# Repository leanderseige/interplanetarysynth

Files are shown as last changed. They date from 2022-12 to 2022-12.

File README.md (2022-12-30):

# Interplanetary Synth

This is a DIY synthesizer project based on Bleeptrack's [Picoplanets](https://github.com/bleeptrack/Picoplanet).

Photo Interplanetary Synth

Features:
- 3 voices, polyphonic, based on PWM
- Recording and looped playback of sequences
- Pitch control
- PT2399-based echo/reverb unit
- Sync in/out jacks in order to sync the Interplanetary Synth with other analog synthesizers

After turning the synth on all three voices start in live-mode. When pressing and holding the button, the Picoplanet starts recording what is currently played. After releasing the button the Picoplanet immediately plays what was recorded. Looping starts with the next rising sync edge (after frequency dividing, see circuit). When pressing the button quickly (without touching any touch buttons) the Picoplanet returns into live-mode.

I am sure the software can be improved in several ways. Find the code.py right here in the root directory.

LEDs:
- Blue: live-mode, synth outputs what is currently played on the touch buttons
- Red: recording of what is currently played on the touch buttons
- Green: playback of recorded frequencies
- Purple: waiting for next rising edge of sync signal to restart playback

## Demo Video

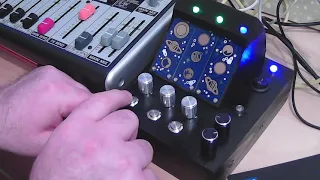
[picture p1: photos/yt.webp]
Demo Video (https://www.youtube.com/watch?v=XGoNoBU3fJs)


Here is a demo of how to use the Interplanetary Synth and how it sounds: https://www.youtube.com/watch?v=XGoNoBU3fJs

## Circuit Diagram

I hope that I have reproduced everything correctly in the circuit diagram. Use at your own risk.

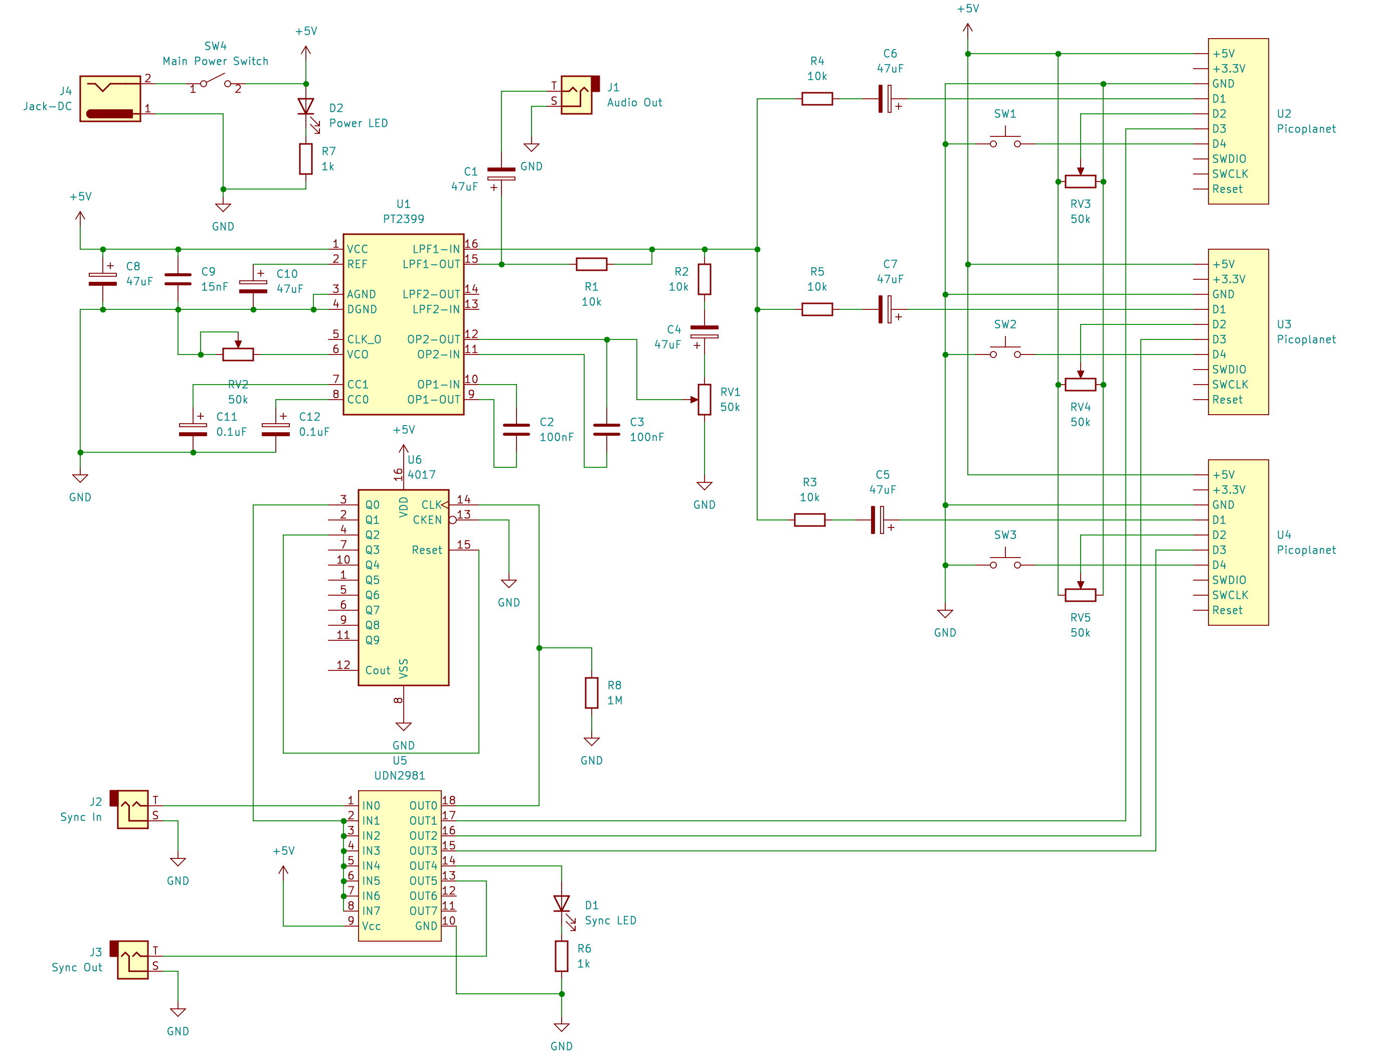
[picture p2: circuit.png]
Circuit Diagram of the Interplanetary Synth


The circuit consists of
- three Picoplanets,
- an Echo/Reverb unit (inspired by Peter Vis' https://www.petervis.com/guitar-circuits/pt2399/testing-and-troubleshooting.html but with important changes on Pins 2, 3 and 4 according to https://www.petervis.com/guitar-circuits/pt2399/basic-echo-circuit.html) and
- a unit to handle Sync signals using a CD4017 (frequency divider) and a UDN2981 (driver)

The four usable Pins of the Picoplanets work as PWM-Output, Potentiometer-Input, Push-Button-Input and Sync-Signal-Input.

## Case

I used a simple wooden box (https://amzn.to/3G5dJ2B) for housing everything except the Picoplanets and I painted it black. In order to get them up at a 45° angle to the user, I designed and printed a special top-case. Find the model in the folder '3dmodels'.

To make the LEDs visible, I drilled additional 5mm holes in the top case (I had forgotten to do this before) and pressed small pieces of 5mm fibre optic cable (https://amzn.to/3QgvRLP) into them. This worked surprisingly well. The light of the small LED appears really great at the end of the fibre cables.

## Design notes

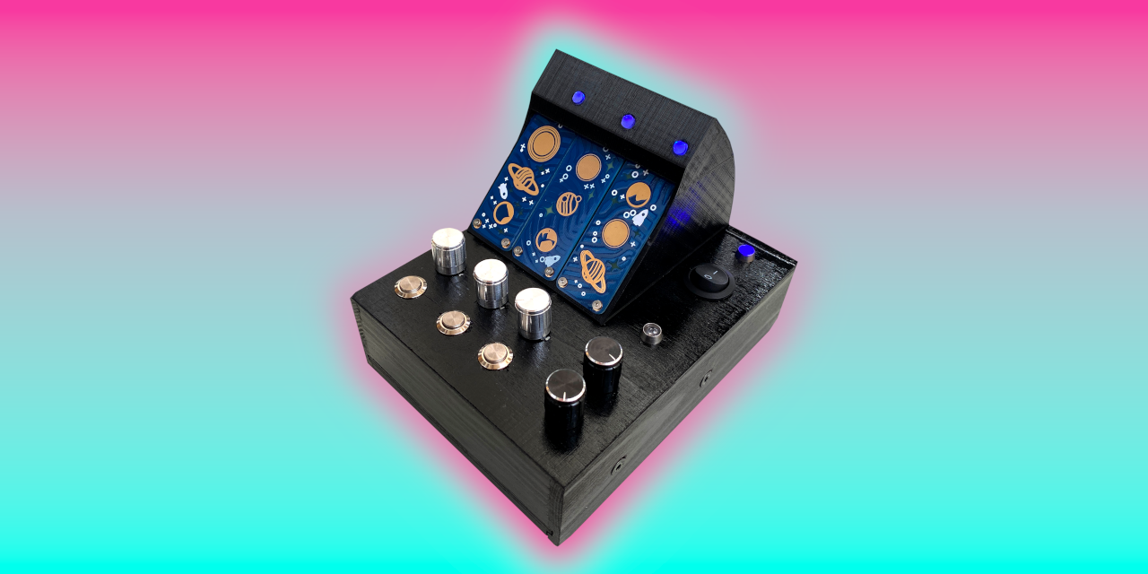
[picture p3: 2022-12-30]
photos/socialmedia.png

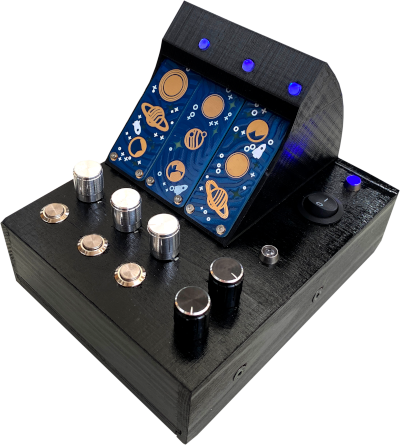
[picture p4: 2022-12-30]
photos/photo1small.png

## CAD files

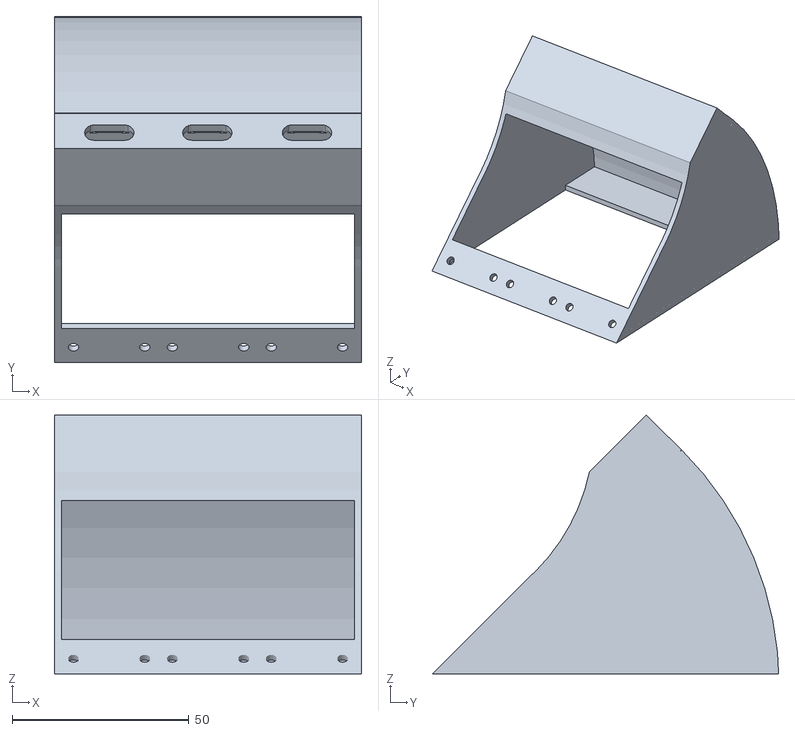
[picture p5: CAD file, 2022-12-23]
3dmodels/topcase.stl
87.0 x 98.0 x 73.3

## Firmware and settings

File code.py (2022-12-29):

#
# Software of the Interplanetary Synth, (c) 2022, Leander Seige
# Released under the terms of the GNU GPL V3
# https://github.com/leanderseige/interplanetarysynth
#
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

import math
import pwmio
import board
import time
import touchio
from digitalio import DigitalInOut, Direction, Pull
import analogio

# init buttons

touch1 = touchio.TouchIn(board.A0)
touch2 = touchio.TouchIn(board.A1)
touch3 = touchio.TouchIn(board.A2)

# D1: init pwm (sound out)

pwmspk1 = pwmio.PWMOut(board.D1, duty_cycle=0x7fff, frequency=440, variable_frequency=True)

# D2: init potentiometer

apin = analogio.AnalogIn(board.A4) # this is D2

# D3: init sync in

syncin = DigitalInOut(board.D3)
syncin.direction = Direction.INPUT
syncin.pull = Pull.DOWN # None doesn't work for me

# D4: init push switch

switch = DigitalInOut(board.D4)
switch.direction = Direction.INPUT
switch.pull = Pull.UP

# init LEDs

ledR = DigitalInOut(board.D6)
ledR.direction = Direction.OUTPUT
ledG = DigitalInOut(board.D5)
ledG.direction = Direction.OUTPUT
ledB = DigitalInOut(board.D7)
ledB.direction = Direction.OUTPUT

time.sleep(1)  # Sleep for a bit to avoid a race condition on some systems

# turn red = calibration

ledR.value = False # for some reason all pins work inverted for me
ledG.value = True
ledB.value = True

high1 = 0
high2 = 0
high3 = 0

# find low level

for x in range(0,20):
    v = touch1.raw_value
    if v > high1:
        high1 = v
    v = touch2.raw_value
    if v > high2:
        high2 = v
    v = touch3.raw_value
    if v > high3:
        high3 = v
    ledR.value = True
    time.sleep(.05)
    ledR.value = False
    time.sleep(.05)

# global variables

rec_f = {} # recorded frequencies
rec_d = {} # duty cycles ar either 0x7fff or 0 for silence
rec_rc = 0 # recording counter
rec_pc = 0 # playback counter
recmode = "LIVE" # mode of operation

vf = 440
vd = 0x7fff

syncsignal = False # shows a rising edge on the sync signal
synctrigger = True # trigger looped playback

# functions

def play_sound(frequency, duty_cycle): # play a sound for us
    f = math.floor(apin.value/32)
    if f > 10000:
        f = 10000
    if f < 50:
        f = 50
    pwmspk1.frequency = frequency + f
    pwmspk1.duty_cycle = duty_cycle

def wait_sync():
    global syncsignal
    global synctrigger
    global recmode
    for x in range(5):
        if syncin.value==False: # inverted, we should have a switch for this
            # ledR.value = False # just for debugging
            # ledG.value = False
            # ledB.value = False
            if syncsignal==False: # detect rising edge
                syncsignal=True
                if synctrigger==False: # set flag
                    synctrigger=True
                    if recmode=="PLAY" and rec_pc==rec_rc:
                        return # w/o sleeping
        else:
            syncsignal=False
        time.sleep(.01)

while True:

    wait_sync()

    if touch1.raw_value > high1+10:
        vf = touch1.raw_value>>4
        vd = 0x7fff
    elif touch2.raw_value > high2+10:
        vf = touch2.raw_value>>2
        vd = 0x7fff
    elif touch3.raw_value > high3+10:
        vf = touch3.raw_value>>1
        vd = 0x7fff
    else:
        vd = 0

    if (not switch.value) and (recmode=="LIVE" or recmode=="PLAY"):
        # button was pressed but we don't know whether we are actually recording
        recmode="TESTREC"
        ledR.value = False
        ledG.value = True
        ledB.value = True
        rec_rc=0
        rec_f[rec_rc] = vf
        rec_d[rec_rc] = vd
        play_sound(vf,vd)
        if(vd>0): # we have actual input and start recording for real
            recmode="ACTIVEREC"
        rec_pc = 0
    elif (not switch.value) and (recmode=="TESTREC" or recmode=="ACTIVEREC"):
        # button is pressed and we are recording for real
        ledR.value = False
        ledG.value = True
        ledB.value = True
        rec_rc = rec_rc+1
        rec_f[rec_rc] = vf
        rec_d[rec_rc] = vd
        play_sound(vf,vd)
        if(vd>0):
            recmode="ACTIVEREC"
        rec_pc = 0
    elif ((switch.value) and recmode=="TESTREC") or recmode=="LIVE":
        # live mode: nothing is recoded right now so we just play current input data
        recmode="LIVE"
        ledR.value = True
        ledG.value = True
        ledB.value = False
        play_sound(vf,vd)
        rec_rc=0
        rec_pc=0
    elif ((switch.value) and recmode=="ACTIVEREC") or recmode=="PLAY":
        # we are in playback mode
        recmode="PLAY"
        ledR.value = True
        ledG.value = False
        ledB.value = True
        if rec_pc<rec_rc: # play sequence
            # playback of recorded frequencies
            rec_pc = rec_pc+1
            play_sound(rec_f[rec_pc],rec_d[rec_pc])
            synctrigger=False # we got it
        elif rec_pc==rec_rc and synctrigger==True:
            # end of recording was reached and sync is true so we are going to restart playback
            rec_pc = 0 # restart
            play_sound(rec_f[rec_pc],rec_d[rec_pc])
            synctrigger=False # we got it
        else: # rec_pc==rec_rc and synctrigger==False
            # end of recording was reached but not sync signal happened, so we wait and play silence
            ledR.value = False
            ledG.value = True
            ledB.value = False
            play_sound(440,0) # silence

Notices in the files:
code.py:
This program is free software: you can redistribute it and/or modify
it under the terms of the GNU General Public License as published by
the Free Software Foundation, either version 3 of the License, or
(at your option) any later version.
